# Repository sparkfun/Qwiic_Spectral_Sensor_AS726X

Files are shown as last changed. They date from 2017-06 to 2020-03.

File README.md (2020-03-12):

SparkFun Qwiic Spectral Sensor AS726X
========================================

<table class="table table-hover table-striped table-bordered">
  <tr>
   <td><a href="https://www.sparkfun.com/products/14347"><div align="center">SparkFun Spectral Sensor Breakout - AS7262 Visible (Qwiic)</div></a></center></td>
   <td><a href="https://www.sparkfun.com/products/14351"><div align="center">SparkFun Spectral Sensor Breakout - AS7263 NIR (Qwiic)</div></a></td>
  </tr>
  <tr>
    <td><div align="center"> <a href="https://www.sparkfun.com/products/14347">SparkFun Spectral Sensor Breakout - AS7262 Visible (Qwiic) (SEN-14347)</a></div></td>
    <td><div align="center"> <a href="https://www.sparkfun.com/products/14351">SparkFun Spectral Sensor Breakout - AS7263 NIR (Qwiic) (SEN-14351)</a></div></td>
  </tr>
</table>

This is the hardware repo for the AS726X Spectral Sensor. The AS7262 version detects wavelengths in the visible range while the AS7263 version detects wavelengths just below the visible range, in the Near Infrared (NIR) range.

Repository Contents
-------------------

* **/Enclosure** - Enclosure files
* **/Firmware** - Example code
* **/Hardware** - Eagle design files (.brd, .sch)
* **/Libraries** - Libraries for use with the AS726X
* **/Production** - Production panel files (.brd)

Documentation
--------------
* **[Library](https://github.com/sparkfun/Sparkfun_AS726X_Arduino_Library)** - Arduino library for the AS726X.
* **[Hookup Guide](https://learn.sparkfun.com/tutorials/as726x-nirvi)** - Basic hookup guide for the AS726X.

Product Versions
----------------
* [SEN-14347](https://www.sparkfun.com/products/14347)- AS7262 Visible Spectral Sensor
* [SEN-14351](https://www.sparkfun.com/products/14351)- AS7263 Near Infrared Spectral Sensor

Version History
---------------
* [V1.0.0](https://github.com/sparkfun/Qwiic_Spectral_Sensor_AS726X/tree/V1.0.0) - Initial Release

License Information
-------------------

This product is _**open source**_! 

Please review the LICENSE.md file for license information. 

If you have any questions or concerns on licensing, please contact technical support on our [SparkFun forums](https://forum.sparkfun.com/viewforum.php?f=152).

Distributed as-is; no warranty is given.

- Your friends at SparkFun.

_<COLLABORATION CREDIT>_

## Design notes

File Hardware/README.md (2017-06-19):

SparkFun <PRODUCT NAME> Design Files
=====================================

The .sch and .brd files hare are Eagle CAD schematic and PCB design files from SparkFun Electronics.
A freeware version of Eagle can be found [here](http://www.cadsoftusa.com/download-eagle/freeware/).

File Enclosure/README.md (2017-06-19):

Enclosure directory.
====================

For any 3D files/models of enclosures that are included with products. 
For example, the casing for the MicroView.

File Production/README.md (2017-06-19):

SparkFun <PRODUCT NAME> Production Files
=========================================

These are the production files SparkFun uses for printing PCBs.

License Information
-------------------
This product is open source! 

The hardware is released under [Creative Commons ShareAlike 4.0 International](https://creativecommons.org/licenses/by-sa/4.0/).

Please use, reuse, and modify these files as you see fit. Please maintain attribution to SparkFun Electronics and release anything derivative under the same license.

Distributed as-is; no warranty is given.

- Your friends at SparkFun.

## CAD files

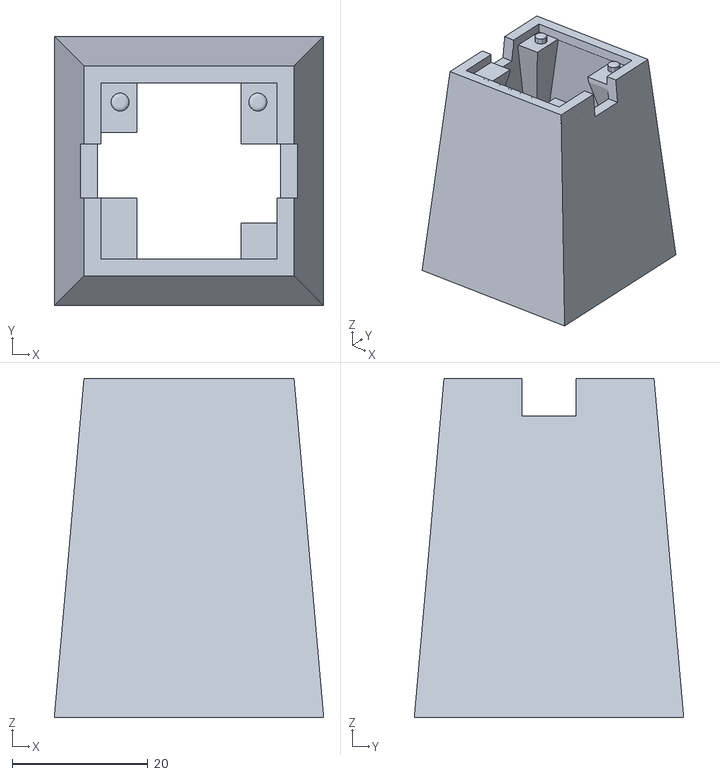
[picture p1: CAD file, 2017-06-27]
Enclosure/AS726xBasicShroud.stl
39.7 x 39.7 x 50.0

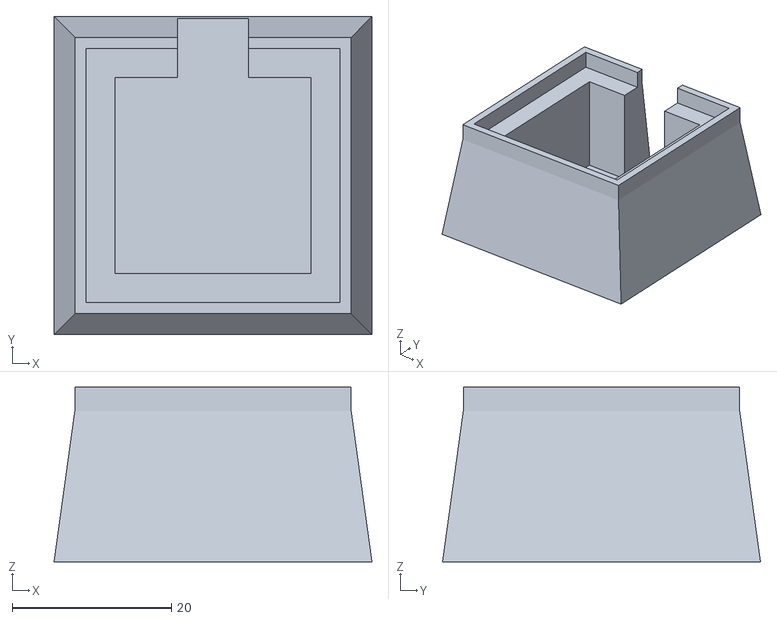
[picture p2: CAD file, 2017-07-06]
Enclosure/Programmer/AS726xProgrammerBase.stl
40.0 x 40.0 x 22.0

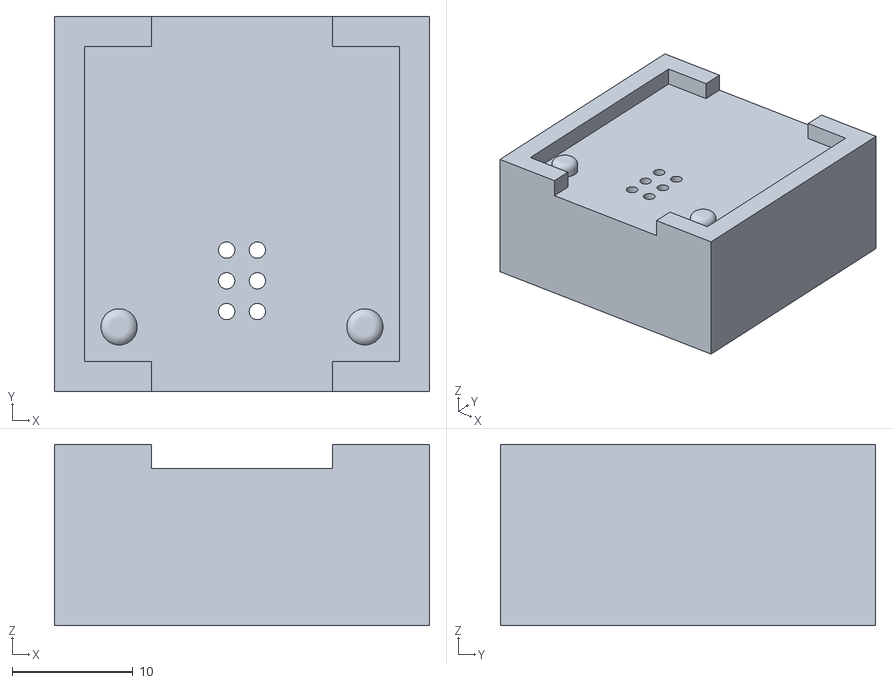
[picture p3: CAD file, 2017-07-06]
Enclosure/Programmer/AS726xProgrammerLid.stl
31.0 x 31.0 x 15.0

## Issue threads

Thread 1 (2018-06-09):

Calibrated and un-calibrated data

vangalvin, 2018-06-09:
I am using an AS7263 and was trying to do a comparison with the calibrated and uncalibrated data however both seem to have exactly the same output?

The other issue I am seeing is that when using sensor.printMeasurements();  the results are a reading with 2 decimal places however when using sensor.getR() there are no decimal places.

nseidle, 2018-06-09:
Uncal data are ints, cal data are floats so I would be surprised if they had identical output. Can you share your code so we can replicate your issue?

Sorry! There's an error in printMeasurements() - [these lines](https://github.com/sparkfun/SparkFun_AS726X_Arduino_Library/blob/master/src/AS726X.cpp#L166) should not be printing a float (the ', 2') since getR() returns an int. Use

    Serial.print(sensor.getR());

instead. We'll get this fixed shortly.

vangalvin, 2018-06-09:
Thanks, This morning when i turned the unit on it out of the blue I am getting a different reading from the sensors. Looks like I am however going to have to use the AT interface as I need to use both the AS7262 and AS7263 at the same time and need to make the circuit as small as possible so a MUX is not really going to be an option and there seems to be no way to change the i2c address.

The the readings I am getting from the AS7263 are as follows.
`Un-Calibrated Data - AS7263 - using getX()
UR: 146 US: 57 UT: 15 UU: 11 UV: 10 UW: 5
Calibrated Data - AS7263 - using getCalibratedX()
CR: 202.37 CS: 63.75 CT: 17.23 CU: 10.74 CV: 10.51 CW: 6.21
Un-Calibrated Data - AS726X - using printUncalibratedMeasurements();
Reading: R[10010010] S[111001] T[1111] U[1011] V[1010] W[101] tempF[69.8]
Calibrated Data - AS726X - using printMeasurements()
Reading: R[202.37] S[63.75] T[17.23] U[10.74] V[10.51] W[6.21] tempF[68.0]

Calibrated Data - AS7262 - using getCalibratedXColourX]()
CV: 414.04 CB: 346.99 CG: 401.32 CY: 405.83 CO: 377.95 CR: 209.68
Calibrated Data - AS7262 - using getXColourX()
UV: 346 UB: 277 UG: 350 UY: 424 UO: 369 UR: 235
Un-Calibrated Data - AS726X - using printUncalibratedMeasurements();
Reading: V[101011010] B[100010110] G[101011110] Y[110101000] O[101110001] R[11101011] tempF[64.4]
Calibrated Data - AS726X - using printMeasurements()
Reading: V[414.04] B[348.24] G[401.32] Y[405.83] O[377.95] R[209.68] tempF[62.6]`

The test code I put together is noting special as I decided to step back and make sure the sensors were working correctly and isolate and possibility of something in my main code causing issues. What was strange is in my main code the output for printUncalibratedMeasurements(); was initially not binary.

`#include "AS726X.h"
AS726X sensor;

byte GAIN = 2;
byte MEASUREMENT_MODE = 3;
byte dump = 1;
void setup() {
    sensor.begin(Wire, GAIN, MEASUREMENT_MODE);
}

void loop() {
    sensor.takeMeasurementsWithBulb();
delay(200);
if(dump == 0){
  Serial.println("Un-Calibrated Data - AS726X - using printUncalibratedMeasurements();");
  sensor.printUncalibratedMeasurements();
  Serial.println("Calibrated Data - AS726X - using printMeasurements()");
  sensor.printMeasurements();
}
if(dump == 1){
    Serial.println("Calibrated Data - AS7262 - using getCalibratedXColourX()");
    Serial.print("CV: ");
    Serial.print(sensor.getCalibratedViolet(), 2);
    Serial.print(" CB: ");
    Serial.print(sensor.getCalibratedBlue(), 2);
    Serial.print(" CG: ");
    Serial.print(sensor.getCalibratedGreen(), 2);
    Serial.print(" CY: ");
    Serial.print(sensor.getCalibratedYellow(), 2);
    Serial.print(" CO: ");
    Serial.print(sensor.getCalibratedOrange(), 2);
    Serial.print(" CR: ");
    Serial.println(sensor.getCalibratedRed(), 2);
    Serial.println("Calibrated Data - AS7262 - using getXColourX()");
    Serial.print("UV: ");
    Serial.print(sensor.getViolet());
    Serial.print(" UB: ");
    Serial.print(sensor.getBlue());
    Serial.print(" UG: ");
    Serial.print(sensor.getGreen());
    Serial.print(" UY: ");
    Serial.print(sensor.getYellow());
    Serial.print(" UO: ");
    Serial.print(sensor.getOrange());
    Serial.print(" UR: ");
    Serial.println(sensor.getRed());
}
if(dump == 2){
    Serial.println("Un-Calibrated Data - AS7263 - using getX()");
    Serial.print("UR: ");
    Serial.print(sensor.getR());
    Serial.print(" US: ");
    Serial.print(sensor.getS());
    Serial.print(" UT: ");
    Serial.print(sensor.getT());
    Serial.print(" UU: ");
    Serial.print(sensor.getU());
    Serial.print(" UV: ");
    Serial.print(sensor.getV());
    Serial.print(" UW: ");
    Serial.println(sensor.getW());
    Serial.println("Calibrated Data - AS7263 - using getCalibratedX()");
    Serial.print("CR: ");
    Serial.print(sensor.getCalibratedR(), 2);
    Serial.print(" CS: ");
    Serial.print(sensor.getCalibratedS(), 2);
    Serial.print(" CT: ");
    Serial.print(sensor.getCalibratedT(), 2);
    Serial.print(" CU: ");
    Serial.print(sensor.getCalibratedU(), 2);
    Serial.print(" CV: ");
    Serial.print(sensor.getCalibratedV(), 2);
    Serial.print(" CW: ");
    Serial.println(sensor.getCalibratedW(), 2);
}
}
`

nseidle, 2018-06-10:
WRT to two sensors on the same bus: There is not a command to easily change the I2C address but the [sensor's firmware](https://github.com/sparkfun/Qwiic_Spectral_Sensor_AS726X/blob/master/Firmware/Firmware%20for%20AT25SF041/AS7262/ams_SDldr_AS7262_v2p0p3_Flash_512K.BIN) (provided by AMS) is programmed on to the SPI flash as the breakout board exits our production line. You *could* modify the hex firmware (the I2C address has to be in there somewhere) and then reprogram one of your boards. Just a wild thought.

vangalvin, 2018-06-10:
@nseidle Had a quick look and noting really jumps out, did a search for the address but cant seem to find it. Its a shame ams has not released the source for this as it would definatly be handy.
If i can find it and are able to change it will let you know as i think there are a few others out there who are having a similar issue from what I have seen. Most however have opted to use an I2C mux.

shintaehwan, 2018-11-27:
i want use my as7263..with mega.. but i don.t know how to use ...
can i know arduino code ? ...
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

nseidle, 2018-11-28:
I'm going to close this issue since the original issue was an I2C address issue that can be solved with a [Qwiic mux](https://www.sparkfun.com/products/14685).

@shintaehwan - We offer an [Arduino library](https://github.com/sparkfun/SparkFun_AS726X_Arduino_Library) that you can install via the Arduino library manager. Please see the [hookup guide](https://learn.sparkfun.com/tutorials/as726x-nirvi) for more info.

shintaehwan, 2018-11-28:
[image: image.png]
[image: image.png]

2018년 11월 28일 (수) 오전 11:40, Nathan Seidle <notifications@github.com>님이 작성:

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

kbickham, 2019-07-28:
Buying a product to multiplex instead of changing an i2c address is not a real solution.

Closed 2018-11-28.

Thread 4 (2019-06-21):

Incompatible with Artemis

nseidle, 2019-06-21:
Board isn't working with Artemis. I'm not entirely sure where it's failing but there's a handful of issues with this lib that might be part of it:

* Don't Wire.begin inside a library
* Don't Serial.print inside a library
* Create functions called setGain(), setMeasurementMode(). Don't pass to begin.
* Consider an .available() function if sensor takes time to take measurement. Don't write blocking code if possible.

Nits:

* Re-write example one to return sensor values. Let user print what they want.
* Please expand on the library.properties paragraph.
* Please name library with what it does (I recommend "SparkFun AS726x Spectral Sensor")

bboyho, 2020-03-12:
I briefly checked in with Andy and it looks like most of these issues were addressed in [https://github.com/sparkfun/SparkFun_AS726X_Arduino_Library/issues/1](https://github.com/sparkfun/SparkFun_AS726X_Arduino_Library/issues/1) and the library updates [https://github.com/sparkfun/SparkFun_AS726X_Arduino_Library/releases](https://github.com/sparkfun/SparkFun_AS726X_Arduino_Library/releases):

* Compiling for Artemis
* Don't Wire.begin inside a library
* Don't Serial.print inside a library
* Consider an .available() function if sensor takes time to take measurement. Don't write blocking code if possible.

stephenf7072, 2020-06-05:
Confirming that I've had it working with the Artemis for a good couple of months (the issue can probably be closed).

nseidle, 2020-06-05:
@stephenf7072 - Thanks for the reminder and test confirmation! Closing.

Closed 2020-06-05.

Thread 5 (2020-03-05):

I2C_AS72XX_SLAVE_STATUS_REG returns 0x82

jajberni, 2020-03-05:
Normally the device works without problems, but after some hours of continuous operation, the device stops.

I noticed that reading the I2C_AS72XX_SLAVE_STATUS_REG returns 0x82 no matter what. Therefore, the condition `if ((status & I2C_AS72XX_SLAVE_TX_VALID) == 0)` is never met in the virtualReadRegister operations.

Is there a way to 'soft reset' the device without using the virtual register operations?

A hard reset normally fits the issue, but it comes back at some point.

nseidle, 2020-03-05:
Yep. Please see [softReset()](https://github.com/sparkfun/SparkFun_AS726X_Arduino_Library/blob/master/src/AS726X.cpp#L292).

jajberni, 2020-03-06:
Unfortunately, this function uses the function [uint8_t AS726X::virtualReadRegister(uint8_t virtualAddr)](https://github.com/sparkfun/SparkFun_AS726X_Arduino_Library/blob/63e75a0c676ab6a9f6aea8fb085095bc575fd7ed/src/AS726X.cpp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), so it doesn't help.

Closed 2020-03-05.

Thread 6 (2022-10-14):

Led no ir source

lavericklavericklaverick, 2022-10-14:
I have had a look at the schematic for the AS7263 NIR spectral sensor and it uses a luxeon 3014 LED, however page 6 of the datsheet [https://lumileds.com/wp-content/uploads ... S208-L.pdf](https://lumileds.com/wp-content/uploads/files/DS208-L.pdf) shows that it does not emit light at 860nm, however the sensor says it can record light at 610, 680, 730, 760, 810 and 860nm - https://www.sparkfun.com/products/14351 is this just using ambient light?

Many thanks

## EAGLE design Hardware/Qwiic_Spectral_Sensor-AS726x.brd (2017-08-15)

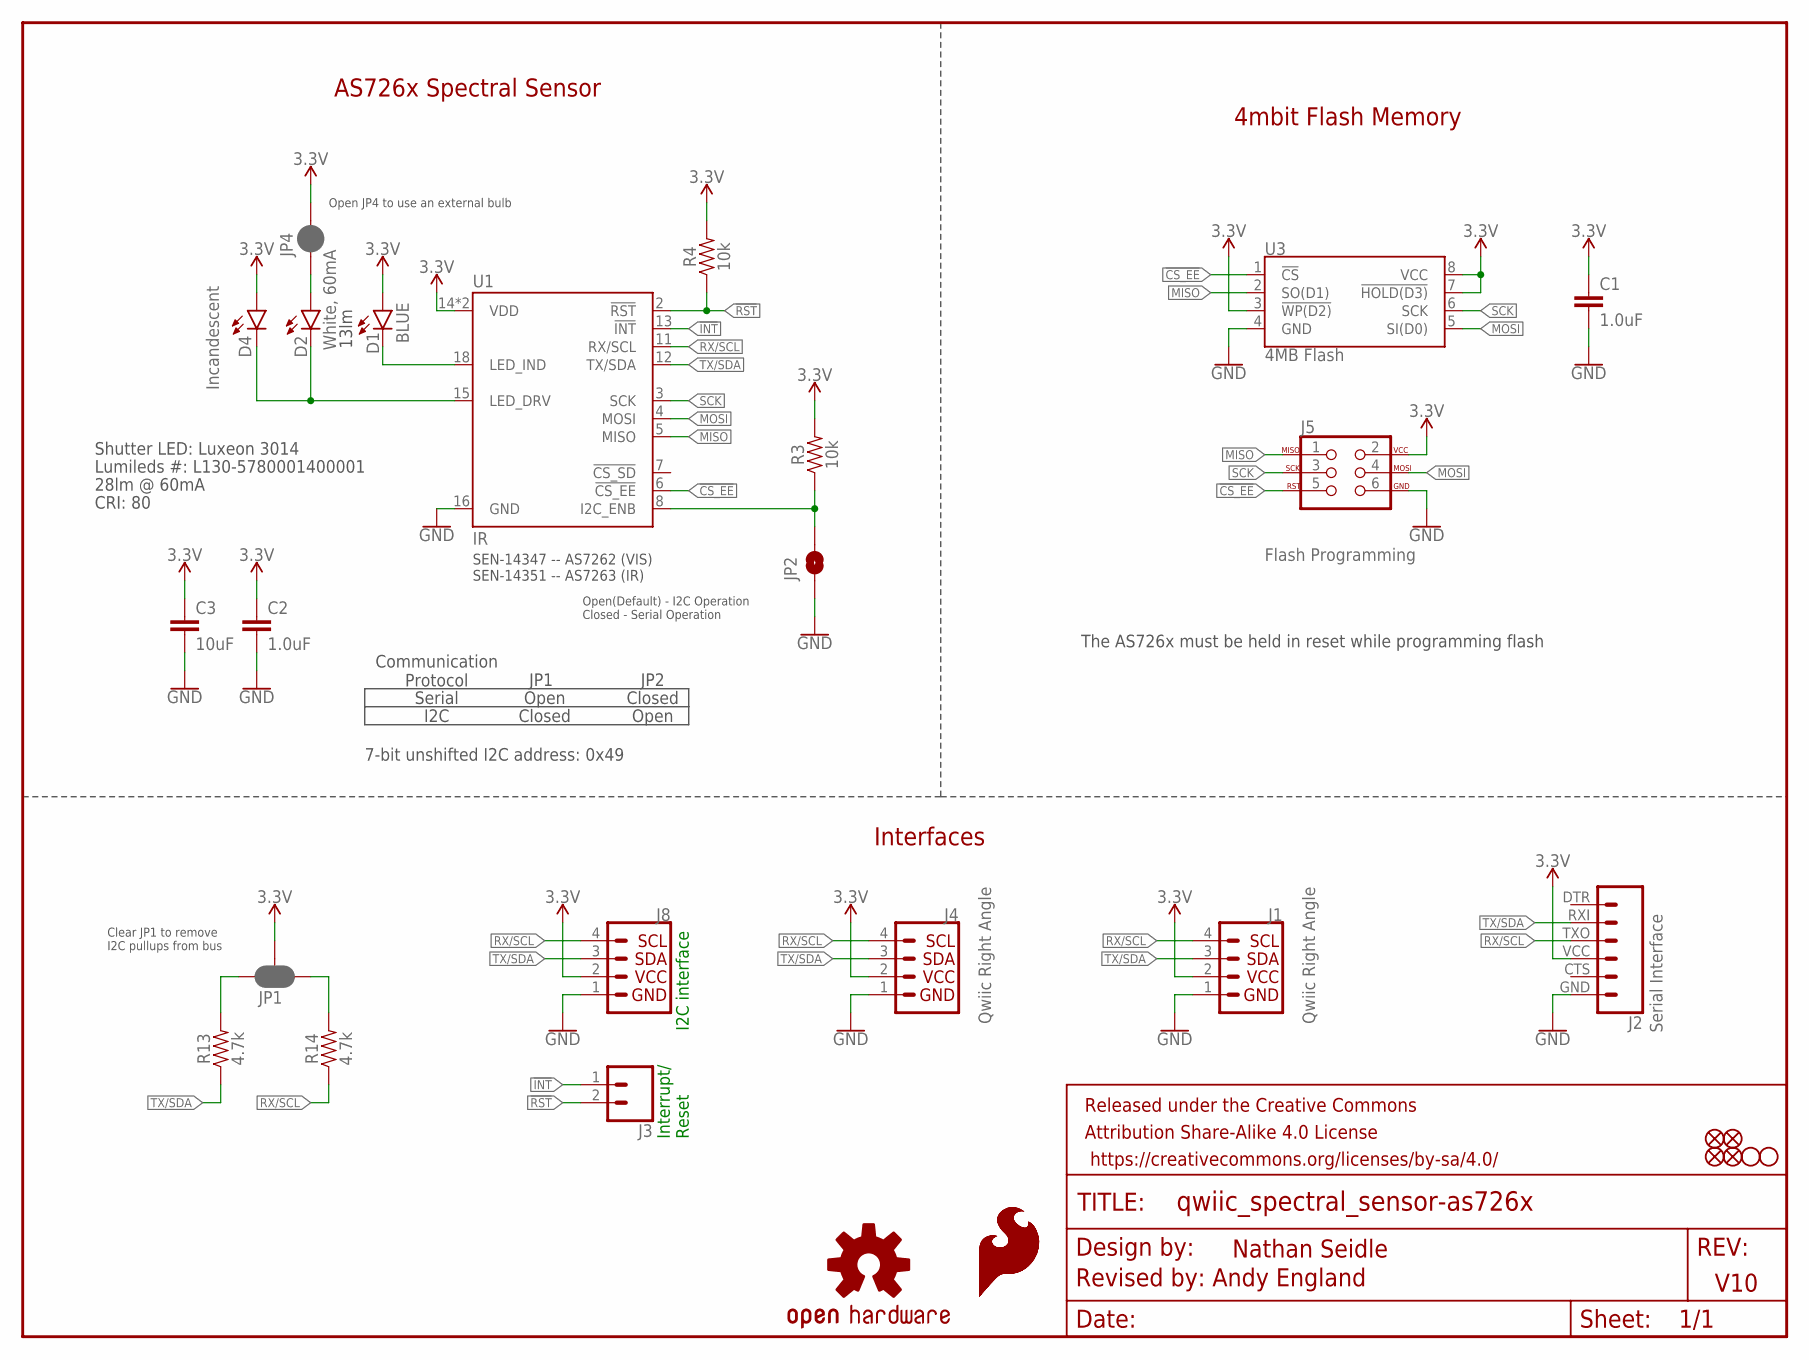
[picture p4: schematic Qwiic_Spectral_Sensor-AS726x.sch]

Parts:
C1, C2: 1.0uF; 0603
C3: 10uF; 0603
D1: BLUE; LED-0603
D2: White, 60mA; SUPER_BRIGHT_SMD_LED_3014
D4: Incandescent; LED_5MM_NOSILK
FD1, FD2, FD3, FD4: FIDUCIAL1X2; FIDUCIAL-1X2
FRAME1: FRAME-LETTER; CREATIVE_COMMONS
H2, H4: STAND-OFF
J1, J4: Qwiic Right Angle; 1X04_1MM_RA
J2: Serial Interface; FTDI_BASIC
J3: CONN_021X02_NO_SILK; 1X02_NO_SILK
J5: Flash Programming; 2X3_TEST_POINTS
J8: I2C_STANDARD_NO_SILK; 1X04_NO_SILK
JP1: JUMPER-SMT_3_2-NC_PASTE_SILK; SMT-JUMPER_3_2-NC_PASTE_SILK
JP2: JUMPER-SMT_2_NO_SILK; SMT-JUMPER_2_NO_SILK
JP4: JUMPER-SMT_2_NC_PASTE_NO-SILK; SMT-JUMPER_2_NC_PASTE_NO-SILK
LOGO1, LOGO2: SFE_LOGO_FLAME.2_INCH; SFE_LOGO_FLAME_.2
LOGO4: OSHW-LOGOS; OSHW-LOGO-S
R3, R4: 10k; 0603
R13, R14: 4.7k; 0603
U1: IR; LGA20
U3: 4MB Flash; SO08

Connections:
3.3V: C1.1, C2.1, C3.1, D1.A, D4.A, J1.2, J2.VCC (4), J4.2, J5.2, J8.2, JP1.2, JP4.2, R3.2, R4.2, U1.14 (VDD), U1.17 (VDD), U3.3 (!WP(D2)), U3.7 (!HOLD(D3)), U3.8 (VCC)
!CS_EE: J5.5, U1.6 (!CS_EE), U3.1 (!CS)
!INT: J3.1, U1.13 (!INT)
!RST: J3.2, R4.1, U1.2 (!RST)
GND: C1.2, C2.2, C3.2, J1.1, J2.GND (6), J4.1, J5.6, J8.1, JP2.1, U1.16 (GND), U3.4 (GND)
LED_DRV: D2.C, D4.K (C), U1.15 (LED_DRV)
MISO: J5.1, U1.5 (MISO), U3.2 (SO(D1))
MOSI: J5.4, U1.4 (MOSI), U3.5 (SI(D0))
unnamed: JP2.2, R3.1, U1.8 (I2C_ENB)
unnamed: D1.C, U1.18 (LED_IND)
unnamed: JP1.3, R13.2
unnamed: JP1.1, R14.2
unnamed: D2.A, JP4.1
RX/SCL: J1.4, J2.TXO (3), J4.4, J8.4, R14.1, U1.11 (RX/SCL)
SCK: J5.3, U1.3 (SCK), U3.6 (SCK)
TX/SDA: J1.3, J2.RXI (2), J4.3, J8.3, R13.1, U1.12 (TX/SDA)

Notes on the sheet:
AS726x Spectral Sensor
Open(Default) - I2C Operation Closed - Serial Operation
Clear JP1 to remove I2C pullups from bus
V10
Nathan Seidle
4mbit Flash Memory
Interfaces
The AS726x must be held in reset while programming flash
Open JP4 to use an external bulb
Serial
JP1
JP2
Open
Closed
Communication Protocol
I2C
13lm
Lumileds #: L130-5780001400001
Shutter LED: Luxeon 3014
28lm @ 60mA
CRI: 80
7-bit unshifted I2C address: 0x49
I2C interface
Interrupt/ Reset
Revised by: Andy England
SEN-14347 -- AS7262 (VIS) SEN-14351 -- AS7263 (IR)

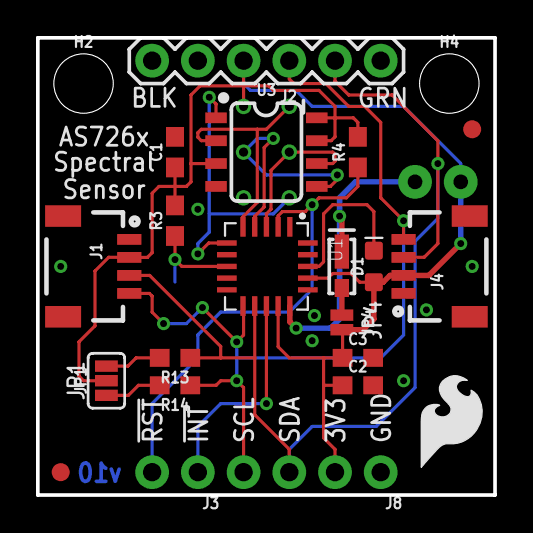
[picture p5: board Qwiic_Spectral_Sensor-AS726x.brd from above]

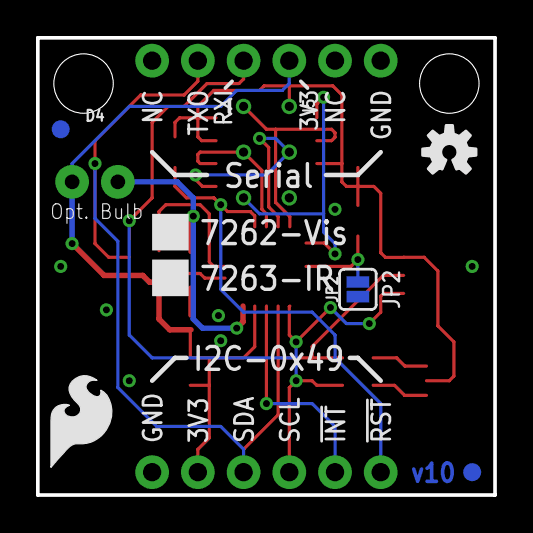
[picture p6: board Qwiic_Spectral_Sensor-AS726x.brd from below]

Board: 2 copper layers, 25.4 x 25.4 mm, 32 parts (7 on the bottom side), 16 nets.

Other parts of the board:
U$2: REVISION

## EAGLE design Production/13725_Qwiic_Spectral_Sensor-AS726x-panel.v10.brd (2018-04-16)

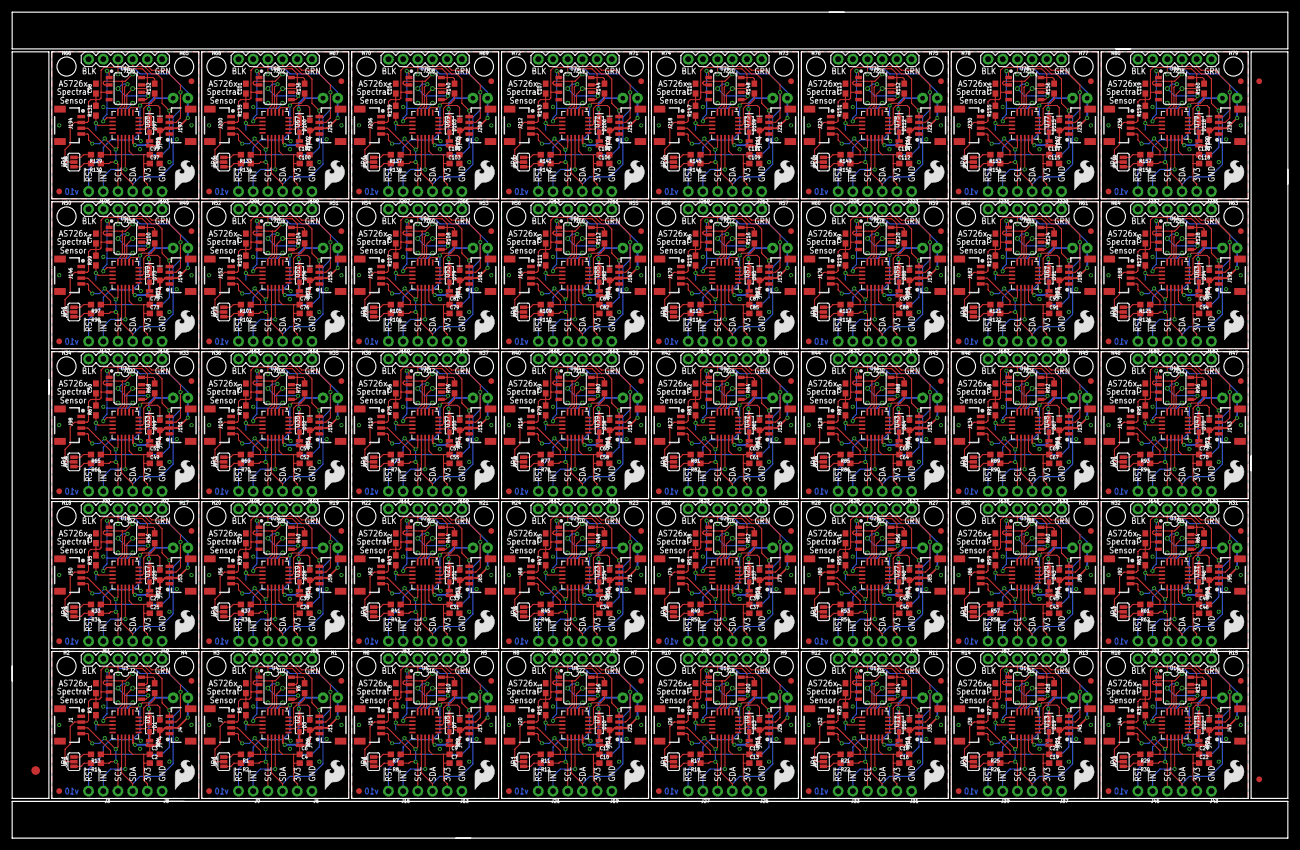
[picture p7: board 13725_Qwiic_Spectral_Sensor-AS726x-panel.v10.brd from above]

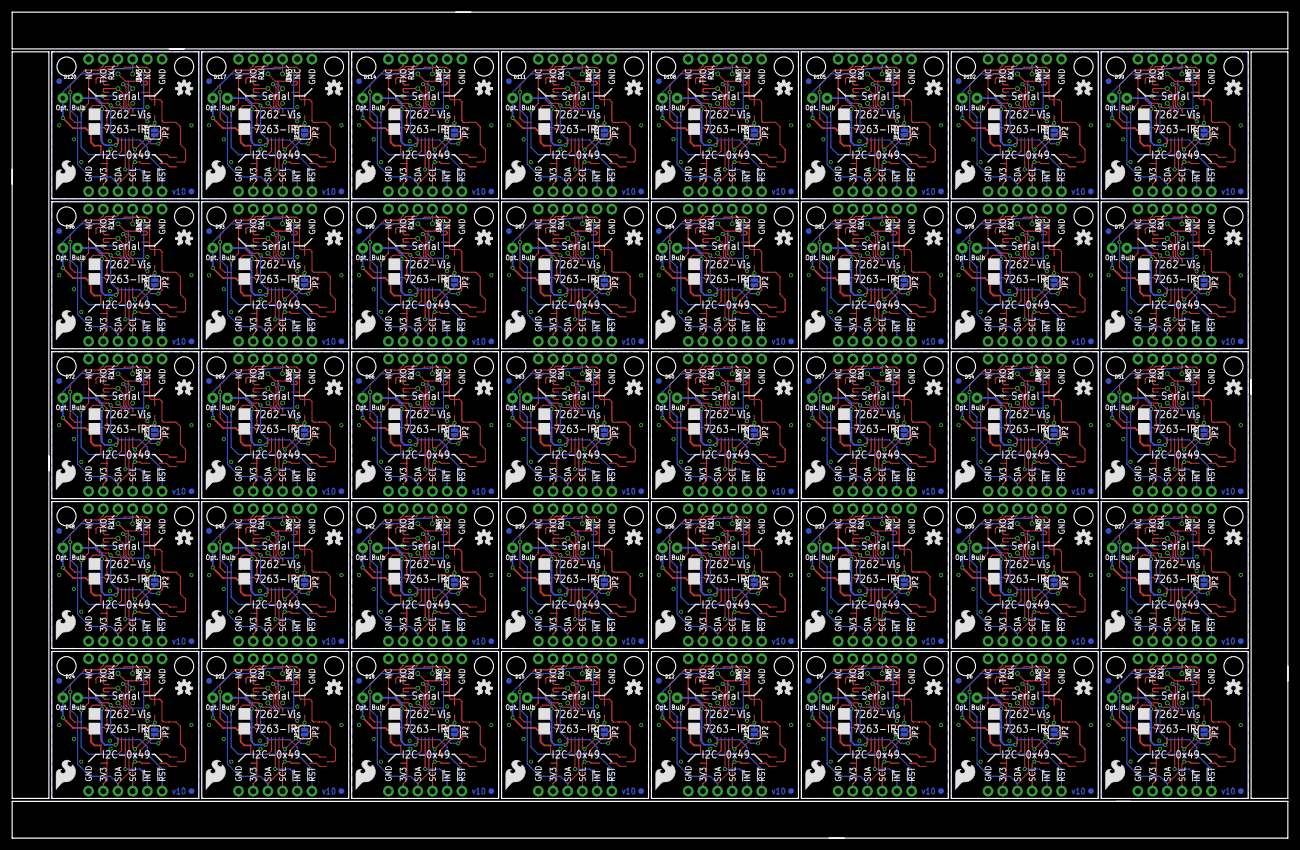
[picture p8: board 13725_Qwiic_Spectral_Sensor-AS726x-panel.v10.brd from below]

Board: 2 copper layers, 220.5 x 142.7 mm, 1203 parts (280 on the bottom side), 640 nets.

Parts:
C1, C2, C4, C5, C7, C8, C10, C11, C13, C14, C16, C17, C19, C20, C22, C23, C25, C26, C28, C29, C31, C32, C34, C35, C37, C38, C40, C41, C43, C44, C46, C47, C49, C50, C52, C53, C55, C56, C58, C59, C61, C62, C64, C65, C67, C68, C70, C71, C73, C74, C76, C77, C79, C80, C82, C83, C85, C86, C88, C89, C91, C92, C94, C95, C97, C98, C100, C101, C103, C104, C106, C107, C109, C110, C112, C113, C115, C116, C118, C119: 1.0uF; 0603
C3, C6, C9, C12, C15, C18, C21, C24, C27, C30, C33, C36, C39, C42, C45, C48, C51, C54, C57, C60, C63, C66, C69, C72, C75, C78, C81, C84, C87, C90, C93, C96, C99, C102, C105, C108, C111, C114, C117, C120: 10uF; 0603
D1, D3, D7, D10, D13, D16, D19, D22, D25, D28, D31, D34, D37, D40, D43, D46, D49, D52, D55, D58, D61, D64, D67, D70, D73, D76, D79, D82, D85, D88, D91, D94, D97, D100, D103, D106, D109, D112, D115, D118: BLUE; LED-0603
D2, D5, D8, D11, D14, D17, D20, D23, D26, D29, D32, D35, D38, D41, D44, D47, D50, D53, D56, D59, D62, D65, D68, D71, D74, D77, D80, D83, D86, D89, D92, D95, D98, D101, D104, D107, D110, D113, D116, D119: White, 60mA; SUPER_BRIGHT_SMD_LED_3014
D4, D6, D9, D12, D15, D18, D21, D24, D27, D30, D33, D36, D39, D42, D45, D48, D51, D54, D57, D60, D63, D66, D69, D72, D75, D78, D81, D84, D87, D90, D93, D96, D99, D102, D105, D108, D111, D114, D117, D120: Incandescent; LED_5MM_NOSILK
E$1: FIDUCIAL-1.5X3
E$7, E$8: FIDUCIAL-1X2
FD1, FD2, FD3, FD4, FD5, FD6, FD7, FD8, FD9, FD10, FD11, FD12, FD13, FD14, FD15, FD16, FD17, FD18, FD19, FD20, FD21, FD22, FD23, FD24, FD25, FD26, FD27, FD28, FD29, FD30, FD31, FD32, FD33, FD34, FD35, FD36, FD37, FD38, FD39, FD40, FD41, FD42, FD43, FD44, FD45, FD46, FD47, FD48, FD49, FD50, FD51, FD52, FD53, FD54, FD55, FD56, FD57, FD58, FD59, FD60, FD61, FD62, FD63, FD64, FD65, FD66, FD67, FD68, FD69, FD70, FD71, FD72, FD73, FD74, FD75, FD76, FD77, FD78, FD79, FD80, FD81, FD82, FD83, FD84, FD85, FD86, FD87, FD88, FD89, FD90, FD91, FD92, FD93, FD94, FD95, FD96, FD97, FD98, FD99, FD100, FD101, FD102, FD103, FD104, FD105, FD106, FD107, FD108, FD109, FD110, FD111, FD112, FD113, FD114, FD115, FD116, FD117, FD118, FD119, FD120, FD121, FD122, FD123, FD124, FD125, FD126, FD127, FD128, FD129, FD130, FD131, FD132, FD133, FD134, FD135, FD136, FD137, FD138, FD139, FD140, FD141, FD142, FD143, FD144, FD145, FD146, FD147, FD148, FD149, FD150, FD151, FD152, FD153, FD154, FD155, FD156, FD157, FD158, FD159, FD160: FIDUCIAL1X2; FIDUCIAL-1X2
H1, H2, H3, H4, H5, H6, H7, H8, H9, H10, H11, H12, H13, H14, H15, H16, H17, H18, H19, H20, H21, H22, H23, H24, H25, H26, H27, H28, H29, H30, H31, H32, H33, H34, H35, H36, H37, H38, H39, H40, H41, H42, H43, H44, H45, H46, H47, H48, H49, H50, H51, H52, H53, H54, H55, H56, H57, H58, H59, H60, H61, H62, H63, H64, H65, H66, H67, H68, H69, H70, H71, H72, H73, H74, H75, H76, H77, H78, H79, H80: STAND-OFF
J1, J4, J7, J11, J14, J17, J20, J23, J26, J29, J32, J35, J38, J41, J44, J47, J50, J53, J56, J59, J62, J65, J68, J71, J74, J77, J80, J83, J86, J89, J92, J95, J98, J101, J104, J107, J110, J113, J116, J119, J122, J125, J128, J131, J134, J137, J140, J143, J146, J149, J152, J155, J158, J161, J164, J167, J170, J173, J176, J179, J182, J185, J188, J191, J194, J197, J200, J203, J206, J209, J212, J215, J218, J221, J224, J227, J230, J233, J236, J239: Qwiic Right Angle; 1X04_1MM_RA
J2, J10, J16, J22, J28, J34, J40, J46, J52, J58, J64, J70, J76, J82, J88, J94, J100, J106, J112, J118, J124, J130, J136, J142, J148, J154, J160, J166, J172, J178, J184, J190, J196, J202, J208, J214, J220, J226, J232, J238: Serial Interface; FTDI_BASIC
J3, J9, J15, J21, J27, J33, J39, J45, J51, J57, J63, J69, J75, J81, J87, J93, J99, J105, J111, J117, J123, J129, J135, J141, J147, J153, J159, J165, J171, J177, J183, J189, J195, J201, J207, J213, J219, J225, J231, J237: 1X02_NO_SILK
J5, J12, J18, J24, J30, J36, J42, J48, J54, J60, J66, J72, J78, J84, J90, J96, J102, J108, J114, J120, J126, J132, J138, J144, J150, J156, J162, J168, J174, J180, J186, J192, J198, J204, J210, J216, J222, J228, J234, J240: Flash Programming; 2X3_TEST_POINTS
J6, J8, J13, J19, J25, J31, J37, J43, J49, J55, J61, J67, J73, J79, J85, J91, J97, J103, J109, J115, J121, J127, J133, J139, J145, J151, J157, J163, J169, J175, J181, J187, J193, J199, J205, J211, J217, J223, J229, J235: 1X04_NO_SILK
JP1, JP5, JP8, JP11, JP14, JP17, JP20, JP23, JP26, JP29, JP32, JP35, JP38, JP41, JP44, JP47, JP50, JP53, JP56, JP59, JP62, JP65, JP68, JP71, JP74, JP77, JP80, JP83, JP86, JP89, JP92, JP95, JP98, JP101, JP104, JP107, JP110, JP113, JP116, JP119: SMT-JUMPER_3_2-NC_PASTE_SILK
JP2, JP3, JP7, JP10, JP13, JP16, JP19, JP22, JP25, JP28, JP31, JP34, JP37, JP40, JP43, JP46, JP49, JP52, JP55, JP58, JP61, JP64, JP67, JP70, JP73, JP76, JP79, JP82, JP85, JP88, JP91, JP94, JP97, JP100, JP103, JP106, JP109, JP112, JP115, JP118: SMT-JUMPER_2_NO_SILK
JP4, JP6, JP9, JP12, JP15, JP18, JP21, JP24, JP27, JP30, JP33, JP36, JP39, JP42, JP45, JP48, JP51, JP54, JP57, JP60, JP63, JP66, JP69, JP72, JP75, JP78, JP81, JP84, JP87, JP90, JP93, JP96, JP99, JP102, JP105, JP108, JP111, JP114, JP117, JP120: SMT-JUMPER_2_NC_PASTE_NO-SILK
LOGO1, LOGO2, LOGO5, LOGO6, LOGO8, LOGO9, LOGO11, LOGO12, LOGO14, LOGO15, LOGO17, LOGO18, LOGO20, LOGO21, LOGO23, LOGO24, LOGO26, LOGO27, LOGO29, LOGO30, LOGO32, LOGO33, LOGO35, LOGO36, LOGO38, LOGO39, LOGO41, LOGO42, LOGO44, LOGO45, LOGO47, LOGO48, LOGO50, LOGO51, LOGO53, LOGO54, LOGO56, LOGO57, LOGO59, LOGO60, LOGO62, LOGO63, LOGO65, LOGO66, LOGO68, LOGO69, LOGO71, LOGO72, LOGO74, LOGO75, LOGO77, LOGO78, LOGO80, LOGO81, LOGO83, LOGO84, LOGO86, LOGO87, LOGO89, LOGO90, LOGO92, LOGO93, LOGO95, LOGO96, LOGO98, LOGO99, LOGO101, LOGO102, LOGO104, LOGO105, LOGO107, LOGO108, LOGO110, LOGO111, LOGO113, LOGO114, LOGO116, LOGO117, LOGO119, LOGO120: SFE_LOGO_FLAME.2_INCH; SFE_LOGO_FLAME_.2
LOGO3, LOGO4, LOGO7, LOGO10, LOGO13, LOGO16, LOGO19, LOGO22, LOGO25, LOGO28, LOGO31, LOGO34, LOGO37, LOGO40, LOGO43, LOGO46, LOGO49, LOGO52, LOGO55, LOGO58, LOGO61, LOGO64, LOGO67, LOGO70, LOGO73, LOGO76, LOGO79, LOGO82, LOGO85, LOGO88, LOGO91, LOGO94, LOGO97, LOGO100, LOGO103, LOGO106, LOGO109, LOGO112, LOGO115, LOGO118: OSHW-LOGOS; OSHW-LOGO-S
R1, R2, R7, R8, R11, R12, R13, R14, R17, R18, R21, R22, R25, R26, R29, R30, R33, R34, R37, R38, R41, R42, R45, R46, R49, R50, R53, R54, R57, R58, R61, R62, R65, R66, R69, R70, R73, R74, R77, R78, R81, R82, R85, R86, R89, R90, R93, R94, R97, R98, R101, R102, R105, R106, R109, R110, R113, R114, R117, R118, R121, R122, R125, R126, R129, R130, R133, R134, R137, R138, R141, R142, R145, R146, R149, R150, R153, R154, R157, R158: 4.7k; 0603
R3, R4, R5, R6, R9, R10, R15, R16, R19, R20, R23, R24, R27, R28, R31, R32, R35, R36, R39, R40, R43, R44, R47, R48, R51, R52, R55, R56, R59, R60, R63, R64, R67, R68, R71, R72, R75, R76, R79, R80, R83, R84, R87, R88, R91, R92, R95, R96, R99, R100, R103, R104, R107, R108, R111, R112, R115, R116, R119, R120, R123, R124, R127, R128, R131, R132, R135, R136, R139, R140, R143, R144, R147, R148, R151, R152, R155, R156, R159, R160: 10k; 0603
U1, U2, U5, U7, U9, U11, U13, U15, U17, U19, U21, U23, U25, U27, U29, U31, U33, U35, U37, U39, U41, U43, U45, U47, U49, U51, U53, U55, U57, U59, U61, U63, U65, U67, U69, U71, U73, U75, U77, U79: IR; LGA20
U3, U4, U6, U8, U10, U12, U14, U16, U18, U20, U22, U24, U26, U28, U30, U32, U34, U36, U38, U40, U42, U44, U46, U48, U50, U52, U54, U56, U58, U60, U62, U64, U66, U68, U70, U72, U74, U76, U78, U80: 4MB Flash; SO08

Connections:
3.3V: C1.1, C2.1, C3.1, D1.A, D4.A, J1.2, J2.VCC, J4.2, J5.2, J8.2, JP1.2, JP4.2, R3.2, R4.2, U1.14, U1.17, U3.3, U3.7, U3.8
3.3V1: C4.1, C5.1, C6.1, D3.A, D6.A, J6.2, J7.2, J10.VCC, J11.2, J12.2, JP5.2, JP6.2, R5.2, R6.2, U2.14, U2.17, U4.3, U4.7, U4.8
3.3V2: C7.1, C8.1, C9.1, D7.A, D9.A, J13.2, J14.2, J16.VCC, J17.2, J18.2, JP8.2, JP9.2, R9.2, R10.2, U5.14, U5.17, U6.3, U6.7, U6.8
3.3V3: C10.1, C11.1, C12.1, D10.A, D12.A, J19.2, J20.2, J22.VCC, J23.2, J24.2, JP11.2, JP12.2, R15.2, R16.2, U7.14, U7.17, U8.3, U8.7, U8.8
3.3V4: C13.1, C14.1, C15.1, D13.A, D15.A, J25.2, J26.2, J28.VCC, J29.2, J30.2, JP14.2, JP15.2, R19.2, R20.2, U9.14, U9.17, U10.3, U10.7, U10.8
3.3V5: C16.1, C17.1, C18.1, D16.A, D18.A, J31.2, J32.2, J34.VCC, J35.2, J36.2, JP17.2, JP18.2, R23.2, R24.2, U11.14, U11.17, U12.3, U12.7, U12.8
3.3V6: C19.1, C20.1, C21.1, D19.A, D21.A, J37.2, J38.2, J40.VCC, J41.2, J42.2, JP20.2, JP21.2, R27.2, R28.2, U13.14, U13.17, U14.3, U14.7, U14.8
3.3V7: C22.1, C23.1, C24.1, D22.A, D24.A, J43.2, J44.2, J46.VCC, J47.2, J48.2, JP23.2, JP24.2, R31.2, R32.2, U15.14, U15.17, U16.3, U16.7, U16.8
3.3V8: C25.1, C26.1, C27.1, D25.A, D27.A, J49.2, J50.2, J52.VCC, J53.2, J54.2, JP26.2, JP27.2, R35.2, R36.2, U17.14, U17.17, U18.3, U18.7, U18.8
3.3V9: C28.1, C29.1, C30.1, D28.A, D30.A, J55.2, J56.2, J58.VCC, J59.2, J60.2, JP29.2, JP30.2, R39.2, R40.2, U19.14, U19.17, U20.3, U20.7, U20.8
3.3V10: C31.1, C32.1, C33.1, D31.A, D33.A, J61.2, J62.2, J64.VCC, J65.2, J66.2, JP32.2, JP33.2, R43.2, R44.2, U21.14, U21.17, U22.3, U22.7, U22.8
3.3V11: C34.1, C35.1, C36.1, D34.A, D36.A, J67.2, J68.2, J70.VCC, J71.2, J72.2, JP35.2, JP36.2, R47.2, R48.2, U23.14, U23.17, U24.3, U24.7, U24.8
3.3V12: C37.1, C38.1, C39.1, D37.A, D39.A, J73.2, J74.2, J76.VCC, J77.2, J78.2, JP38.2, JP39.2, R51.2, R52.2, U25.14, U25.17, U26.3, U26.7, U26.8
3.3V13: C40.1, C41.1, C42.1, D40.A, D42.A, J79.2, J80.2, J82.VCC, J83.2, J84.2, JP41.2, JP42.2, R55.2, R56.2, U27.14, U27.17, U28.3, U28.7, U28.8
3.3V14: C43.1, C44.1, C45.1, D43.A, D45.A, J85.2, J86.2, J88.VCC, J89.2, J90.2, JP44.2, JP45.2, R59.2, R60.2, U29.14, U29.17, U30.3, U30.7, U30.8
3.3V15: C46.1, C47.1, C48.1, D46.A, D48.A, J91.2, J92.2, J94.VCC, J95.2, J96.2, JP47.2, JP48.2, R63.2, R64.2, U31.14, U31.17, U32.3, U32.7, U32.8
3.3V16: C49.1, C50.1, C51.1, D49.A, D51.A, J97.2, J98.2, J100.VCC, J101.2, J102.2, JP50.2, JP51.2, R67.2, R68.2, U33.14, U33.17, U34.3, U34.7, U34.8
3.3V17: C52.1, C53.1, C54.1, D52.A, D54.A, J103.2, J104.2, J106.VCC, J107.2, J108.2, JP53.2, JP54.2, R71.2, R72.2, U35.14, U35.17, U36.3, U36.7, U36.8
3.3V18: C55.1, C56.1, C57.1, D55.A, D57.A, J109.2, J110.2, J112.VCC, J113.2, J114.2, JP56.2, JP57.2, R75.2, R76.2, U37.14, U37.17, U38.3, U38.7, U38.8
3.3V19: C58.1, C59.1, C60.1, D58.A, D60.A, J115.2, J116.2, J118.VCC, J119.2, J120.2, JP59.2, JP60.2, R79.2, R80.2, U39.14, U39.17, U40.3, U40.7, U40.8
3.3V20: C61.1, C62.1, C63.1, D61.A, D63.A, J121.2, J122.2, J124.VCC, J125.2, J126.2, JP62.2, JP63.2, R83.2, R84.2, U41.14, U41.17, U42.3, U42.7, U42.8
3.3V21: C64.1, C65.1, C66.1, D64.A, D66.A, J127.2, J128.2, J130.VCC, J131.2, J132.2, JP65.2, JP66.2, R87.2, R88.2, U43.14, U43.17, U44.3, U44.7, U44.8
3.3V22: C67.1, C68.1, C69.1, D67.A, D69.A, J133.2, J134.2, J136.VCC, J137.2, J138.2, JP68.2, JP69.2, R91.2, R92.2, U45.14, U45.17, U46.3, U46.7, U46.8
3.3V23: C70.1, C71.1, C72.1, D70.A, D72.A, J139.2, J140.2, J142.VCC, J143.2, J144.2, JP71.2, JP72.2, R95.2, R96.2, U47.14, U47.17, U48.3, U48.7, U48.8
3.3V24: C73.1, C74.1, C75.1, D73.A, D75.A, J145.2, J146.2, J148.VCC, J149.2, J150.2, JP74.2, JP75.2, R99.2, R100.2, U49.14, U49.17, U50.3, U50.7, U50.8
3.3V25: C76.1, C77.1, C78.1, D76.A, D78.A, J151.2, J152.2, J154.VCC, J155.2, J156.2, JP77.2, JP78.2, R103.2, R104.2, U51.14, U51.17, U52.3, U52.7, U52.8
3.3V26: C79.1, C80.1, C81.1, D79.A, D81.A, J157.2, J158.2, J160.VCC, J161.2, J162.2, JP80.2, JP81.2, R107.2, R108.2, U53.14, U53.17, U54.3, U54.7, U54.8
3.3V27: C82.1, C83.1, C84.1, D82.A, D84.A, J163.2, J164.2, J166.VCC, J167.2, J168.2, JP83.2, JP84.2, R111.2, R112.2, U55.14, U55.17, U56.3, U56.7, U56.8
3.3V28: C85.1, C86.1, C87.1, D85.A, D87.A, J169.2, J170.2, J172.VCC, J173.2, J174.2, JP86.2, JP87.2, R115.2, R116.2, U57.14, U57.17, U58.3, U58.7, U58.8
3.3V29: C88.1, C89.1, C90.1, D88.A, D90.A, J175.2, J176.2, J178.VCC, J179.2, J180.2, JP89.2, JP90.2, R119.2, R120.2, U59.14, U59.17, U60.3, U60.7, U60.8
3.3V30: C91.1, C92.1, C93.1, D91.A, D93.A, J181.2, J182.2, J184.VCC, J185.2, J186.2, JP92.2, JP93.2, R123.2, R124.2, U61.14, U61.17, U62.3, U62.7, U62.8
3.3V31: C94.1, C95.1, C96.1, D94.A, D96.A, J187.2, J188.2, J190.VCC, J191.2, J192.2, JP95.2, JP96.2, R127.2, R128.2, U63.14, U63.17, U64.3, U64.7, U64.8
3.3V32: C97.1, C98.1, C99.1, D97.A, D99.A, J193.2, J194.2, J196.VCC, J197.2, J198.2, JP98.2, JP99.2, R131.2, R132.2, U65.14, U65.17, U66.3, U66.7, U66.8
3.3V33: C100.1, C101.1, C102.1, D100.A, D102.A, J199.2, J200.2, J202.VCC, J203.2, J204.2, JP101.2, JP102.2, R135.2, R136.2, U67.14, U67.17, U68.3, U68.7, U68.8
3.3V34: C103.1, C104.1, C105.1, D103.A, D105.A, J205.2, J206.2, J208.VCC, J209.2, J210.2, JP104.2, JP105.2, R139.2, R140.2, U69.14, U69.17, U70.3, U70.7, U70.8
3.3V35: C106.1, C107.1, C108.1, D106.A, D108.A, J211.2, J212.2, J214.VCC, J215.2, J216.2, JP107.2, JP108.2, R143.2, R144.2, U71.14, U71.17, U72.3, U72.7, U72.8
3.3V36: C109.1, C110.1, C111.1, D109.A, D111.A, J217.2, J218.2, J220.VCC, J221.2, J222.2, JP110.2, JP111.2, R147.2, R148.2, U73.14, U73.17, U74.3, U74.7, U74.8
3.3V37: C112.1, C113.1, C114.1, D112.A, D114.A, J223.2, J224.2, J226.VCC, J227.2, J228.2, JP113.2, JP114.2, R151.2, R152.2, U75.14, U75.17, U76.3, U76.7, U76.8
3.3V38: C115.1, C116.1, C117.1, D115.A, D117.A, J229.2, J230.2, J232.VCC, J233.2, J234.2, JP116.2, JP117.2, R155.2, R156.2, U77.14, U77.17, U78.3, U78.7, U78.8
3.3V39: C118.1, C119.1, C120.1, D118.A, D120.A, J235.2, J236.2, J238.VCC, J239.2, J240.2, JP119.2, JP120.2, R159.2, R160.2, U79.14, U79.17, U80.3, U80.7, U80.8
!CS_EE: J5.5, U1.6, U3.1
!CS_EE1: J12.5, U2.6, U4.1
!CS_EE2: J18.5, U5.6, U6.1
!CS_EE3: J24.5, U7.6, U8.1
!CS_EE4: J30.5, U9.6, U10.1
!CS_EE5: J36.5, U11.6, U12.1
!CS_EE6: J42.5, U13.6, U14.1
!CS_EE7: J48.5, U15.6, U16.1
!CS_EE8: J54.5, U17.6, U18.1
!CS_EE9: J60.5, U19.6, U20.1
!CS_EE10: J66.5, U21.6, U22.1
!CS_EE11: J72.5, U23.6, U24.1
!CS_EE12: J78.5, U25.6, U26.1
!CS_EE13: J84.5, U27.6, U28.1
!CS_EE14: J90.5, U29.6, U30.1
!CS_EE15: J96.5, U31.6, U32.1
!CS_EE16: J102.5, U33.6, U34.1
!CS_EE17: J108.5, U35.6, U36.1
!CS_EE18: J114.5, U37.6, U38.1
!CS_EE19: J120.5, U39.6, U40.1
!CS_EE20: J126.5, U41.6, U42.1
!CS_EE21: J132.5, U43.6, U44.1
!CS_EE22: J138.5, U45.6, U46.1
!CS_EE23: J144.5, U47.6, U48.1
!CS_EE24: J150.5, U49.6, U50.1
!CS_EE25: J156.5, U51.6, U52.1
!CS_EE26: J162.5, U53.6, U54.1
!CS_EE27: J168.5, U55.6, U56.1
!CS_EE28: J174.5, U57.6, U58.1
!CS_EE29: J180.5, U59.6, U60.1
!CS_EE30: J186.5, U61.6, U62.1
!CS_EE31: J192.5, U63.6, U64.1
!CS_EE32: J198.5, U65.6, U66.1
!CS_EE33: J204.5, U67.6, U68.1
!CS_EE34: J210.5, U69.6, U70.1
!CS_EE35: J216.5, U71.6, U72.1
!CS_EE36: J222.5, U73.6, U74.1
!CS_EE37: J228.5, U75.6, U76.1
!CS_EE38: J234.5, U77.6, U78.1
!CS_EE39: J240.5, U79.6, U80.1
!INT: J3.1, U1.13
!INT1: J9.1, U2.13
!INT2: J15.1, U5.13
!INT3: J21.1, U7.13
!INT4: J27.1, U9.13
!INT5: J33.1, U11.13
!INT6: J39.1, U13.13
!INT7: J45.1, U15.13
!INT8: J51.1, U17.13
!INT9: J57.1, U19.13
!INT10: J63.1, U21.13
!INT11: J69.1, U23.13
!INT12: J75.1, U25.13
!INT13: J81.1, U27.13
!INT14: J87.1, U29.13
!INT15: J93.1, U31.13
!INT16: J99.1, U33.13
!INT17: J105.1, U35.13
!INT18: J111.1, U37.13
!INT19: J117.1, U39.13
!INT20: J123.1, U41.13
!INT21: J129.1, U43.13
!INT22: J135.1, U45.13
!INT23: J141.1, U47.13
!INT24: J147.1, U49.13
!INT25: J153.1, U51.13
!INT26: J159.1, U53.13
!INT27: J165.1, U55.13
!INT28: J171.1, U57.13
!INT29: J177.1, U59.13
!INT30: J183.1, U61.13
!INT31: J189.1, U63.13
!INT32: J195.1, U65.13
!INT33: J201.1, U67.13
!INT34: J207.1, U69.13
!INT35: J213.1, U71.13
!INT36: J219.1, U73.13
!INT37: J225.1, U75.13
!INT38: J231.1, U77.13
!INT39: J237.1, U79.13
!RST: J3.2, R4.1, U1.2
!RST1: J9.2, R6.1, U2.2
!RST2: J15.2, R10.1, U5.2
!RST3: J21.2, R16.1, U7.2
!RST4: J27.2, R20.1, U9.2
!RST5: J33.2, R24.1, U11.2
!RST6: J39.2, R28.1, U13.2
!RST7: J45.2, R32.1, U15.2
!RST8: J51.2, R36.1, U17.2
!RST9: J57.2, R40.1, U19.2
!RST10: J63.2, R44.1, U21.2
!RST11: J69.2, R48.1, U23.2
!RST12: J75.2, R52.1, U25.2
!RST13: J81.2, R56.1, U27.2
!RST14: J87.2, R60.1, U29.2
!RST15: J93.2, R64.1, U31.2
!RST16: J99.2, R68.1, U33.2
!RST17: J105.2, R72.1, U35.2
!RST18: J111.2, R76.1, U37.2
!RST19: J117.2, R80.1, U39.2
!RST20: J123.2, R84.1, U41.2
!RST21: J129.2, R88.1, U43.2
!RST22: J135.2, R92.1, U45.2
!RST23: J141.2, R96.1, U47.2
!RST24: J147.2, R100.1, U49.2
!RST25: J153.2, R104.1, U51.2
!RST26: J159.2, R108.1, U53.2
!RST27: J165.2, R112.1, U55.2
!RST28: J171.2, R116.1, U57.2
!RST29: J177.2, R120.1, U59.2
!RST30: J183.2, R124.1, U61.2
!RST31: J189.2, R128.1, U63.2
!RST32: J195.2, R132.1, U65.2
!RST33: J201.2, R136.1, U67.2
!RST34: J207.2, R140.1, U69.2
!RST35: J213.2, R144.1, U71.2
!RST36: J219.2, R148.1, U73.2
!RST37: J225.2, R152.1, U75.2
!RST38: J231.2, R156.1, U77.2
!RST39: J237.2, R160.1, U79.2
GND: C1.2, C2.2, C3.2, J1.1, J2.GND, J4.1, J5.6, J8.1, JP2.1, U1.16, U3.4
GND1: C4.2, C5.2, C6.2, J6.1, J7.1, J10.GND, J11.1, J12.6, JP3.1, U2.16, U4.4
GND2: C7.2, C8.2, C9.2, J13.1, J14.1, J16.GND, J17.1, J18.6, JP7.1, U5.16, U6.4
GND3: C10.2, C11.2, C12.2, J19.1, J20.1, J22.GND, J23.1, J24.6, JP10.1, U7.16, U8.4
GND4: C13.2, C14.2, C15.2, J25.1, J26.1, J28.GND, J29.1, J30.6, JP13.1, U9.16, U10.4
GND5: C16.2, C17.2, C18.2, J31.1, J32.1, J34.GND, J35.1, J36.6, JP16.1, U11.16, U12.4
GND6: C19.2, C20.2, C21.2, J37.1, J38.1, J40.GND, J41.1, J42.6, JP19.1, U13.16, U14.4
GND7: C22.2, C23.2, C24.2, J43.1, J44.1, J46.GND, J47.1, J48.6, JP22.1, U15.16, U16.4
GND8: C25.2, C26.2, C27.2, J49.1, J50.1, J52.GND, J53.1, J54.6, JP25.1, U17.16, U18.4
GND9: C28.2, C29.2, C30.2, J55.1, J56.1, J58.GND, J59.1, J60.6, JP28.1, U19.16, U20.4
GND10: C31.2, C32.2, C33.2, J61.1, J62.1, J64.GND, J65.1, J66.6, JP31.1, U21.16, U22.4
GND11: C34.2, C35.2, C36.2, J67.1, J68.1, J70.GND, J71.1, J72.6, JP34.1, U23.16, U24.4
GND12: C37.2, C38.2, C39.2, J73.1, J74.1, J76.GND, J77.1, J78.6, JP37.1, U25.16, U26.4
GND13: C40.2, C41.2, C42.2, J79.1, J80.1, J82.GND, J83.1, J84.6, JP40.1, U27.16, U28.4
GND14: C43.2, C44.2, C45.2, J85.1, J86.1, J88.GND, J89.1, J90.6, JP43.1, U29.16, U30.4
GND15: C46.2, C47.2, C48.2, J91.1, J92.1, J94.GND, J95.1, J96.6, JP46.1, U31.16, U32.4
GND16: C49.2, C50.2, C51.2, J97.1, J98.1, J100.GND, J101.1, J102.6, JP49.1, U33.16, U34.4
GND17: C52.2, C53.2, C54.2, J103.1, J104.1, J106.GND, J107.1, J108.6, JP52.1, U35.16, U36.4
GND18: C55.2, C56.2, C57.2, J109.1, J110.1, J112.GND, J113.1, J114.6, JP55.1, U37.16, U38.4
GND19: C58.2, C59.2, C60.2, J115.1, J116.1, J118.GND, J119.1, J120.6, JP58.1, U39.16, U40.4
GND20: C61.2, C62.2, C63.2, J121.1, J122.1, J124.GND, J125.1, J126.6, JP61.1, U41.16, U42.4
GND21: C64.2, C65.2, C66.2, J127.1, J128.1, J130.GND, J131.1, J132.6, JP64.1, U43.16, U44.4
GND22: C67.2, C68.2, C69.2, J133.1, J134.1, J136.GND, J137.1, J138.6, JP67.1, U45.16, U46.4
GND23: C70.2, C71.2, C72.2, J139.1, J140.1, J142.GND, J143.1, J144.6, JP70.1, U47.16, U48.4
GND24: C73.2, C74.2, C75.2, J145.1, J146.1, J148.GND, J149.1, J150.6, JP73.1, U49.16, U50.4
GND25: C76.2, C77.2, C78.2, J151.1, J152.1, J154.GND, J155.1, J156.6, JP76.1, U51.16, U52.4
GND26: C79.2, C80.2, C81.2, J157.1, J158.1, J160.GND, J161.1, J162.6, JP79.1, U53.16, U54.4
GND27: C82.2, C83.2, C84.2, J163.1, J164.1, J166.GND, J167.1, J168.6, JP82.1, U55.16, U56.4
GND28: C85.2, C86.2, C87.2, J169.1, J170.1, J172.GND, J173.1, J174.6, JP85.1, U57.16, U58.4
GND29: C88.2, C89.2, C90.2, J175.1, J176.1, J178.GND, J179.1, J180.6, JP88.1, U59.16, U60.4
GND30: C91.2, C92.2, C93.2, J181.1, J182.1, J184.GND, J185.1, J186.6, JP91.1, U61.16, U62.4
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

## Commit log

2017-06-19 Formatted repo
    [Qwiic_Spectral_Sensor-AS726x.brd, Qwiic_Spectral_Sensor-AS726x.sch]
2017-06-19 Updated LED
    [Qwiic_Spectral_Sensor-AS726x.brd, Qwiic_Spectral_Sensor-AS726x.sch]
2017-06-19 Added LED, I2C connectors to SFE library and changed components in schematic
    [Qwiic_Spectral_Sensor-AS726x.brd, Qwiic_Spectral_Sensor-AS726x.sch]
2017-06-20 Updated all schematics to point to proper library
    [Qwiic_Spectral_Sensor-AS726x.brd, Qwiic_Spectral_Sensor-AS726x.sch]
2017-06-26 Fixed minor borad layout issues
    [Qwiic_Spectral_Sensor-AS726x.brd, Qwiic_Spectral_Sensor-AS726x.sch]
2017-06-27 Post design review changes. Cream on JP1 and AS726X still needs to be changed
    [Qwiic_Spectral_Sensor-AS726x.brd, Qwiic_Spectral_Sensor-AS726x.sch]
2017-06-27 Added .stl for enclosure
    [AS726xBasicShroud.stl]
2017-06-28 Made final changes to tCream on AS726X
    [Qwiic_Spectral_Sensor-AS726x.brd, Qwiic_Spectral_Sensor-AS726x.sch]
2017-06-28 Continued to update with checklist
    [Qwiic_Spectral_Sensor-AS726x.brd]
2017-06-28 Misc. changes, post design review
    [Qwiic_Spectral_Sensor-AS726x.brd]
2017-07-03 Final changes before 2nd Design Review
    [Qwiic_Spectral_Sensor-AS726x.brd]
2017-07-05 Final post design review changes
    [Qwiic_Spectral_Sensor-AS726x.brd]
2017-07-06 Changed version number to match SFE style
    [Qwiic_Spectral_Sensor-AS726x.brd, Qwiic_Spectral_Sensor-AS726x.sch]
2017-07-06 Moved enclosure
    [AS726xBasicShroud.stl]
2017-07-06 Added .stl of programmer
    [AS726xProgrammerBase.stl, AS726xProgrammerLid.stl]
2017-07-11 Library Functions, must add Wire selection
2017-07-12 Added non default constructor, License in wrong place
    [Qwiic_Spectral_Sensor-AS726x.sch]
2017-07-19 Added label to JP4
    [Qwiic_Spectral_Sensor-AS726x.brd]
2017-07-21 Changed version number
    [Qwiic_Spectral_Sensor-AS726x.brd, Qwiic_Spectral_Sensor-AS726x.sch]
2017-07-24 Squashed 'Libraries/Arduino/' content from commit c1fc430
    git-subtree-dir: Libraries/Arduino
    git-subtree-split: c1fc4301b125d5a296ba35155b57e9aedd8828c4
2017-07-25 Changed board version
    [Board_Design_Checklist.xls, Board_Design_Checklist_AS726X_.xls, Qwiic_Spectral_Sensor-AS726x.brd]
2017-07-25 Fixed qwiic conn
    [Qwiic_Spectral_Sensor-AS726x.brd, Qwiic_Spectral_Sensor-AS726x.sch]
2017-08-15 changed dimensions
    [Qwiic_Spectral_Sensor-AS726x.brd]
2017-08-23 Moved engineering checklist
    [Board_Design_Checklist.xls, Board_Design_Checklist_AS726X_.xls]
2017-09-12 Squashed 'Libraries/Arduino/' content from commit fdb7230
    git-subtree-split: fdb7230b3d93a20c6f5643e600e2dbba81a91f10
    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
2017-10-19 Updating readme
    [Board_Design_Checklist_AS726X_.xls]
2017-10-19 Squashed 'Libraries/Arduino/' content from commit edc2b6d
    git-subtree-split: edc2b6d7eaa1af2b5196feef1b4779a1a61ffca9
    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
2018-04-16 Triple jumper Aperture blowout
    [13725_Qwiic_Spectral_Sensor-AS726x-panel.v10.brd]
2020-03-12 Remove Outdated Library and Point to Repo for Arduino Library
    Remove outdated library and remove redundancy by pointing to the repository for the Arduino library.

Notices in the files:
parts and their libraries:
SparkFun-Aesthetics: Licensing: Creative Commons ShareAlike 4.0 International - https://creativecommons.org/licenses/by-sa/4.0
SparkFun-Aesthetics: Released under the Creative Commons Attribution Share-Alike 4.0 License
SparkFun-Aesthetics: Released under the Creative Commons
